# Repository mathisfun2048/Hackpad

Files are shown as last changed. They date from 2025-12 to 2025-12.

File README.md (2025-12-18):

# Arya's Hackpad Macropad!

This 9-key macropad also includes a 3x3 led aray, rotary encoder, and an OLED display. It uses KMK Firmware (learning the python library was fun!) This is my first time working with PCB so it was a fun expeirment!

I designed this to help me with photoshop, illustrator, and indesign! I also saw some cool bitmap-pattern led machines at Ikea and wanted to emulate them using a LED array. 

# Features:
- top and bottom parts for the case
- XIAO‑RP2040 as the processor
- 128x32 OLED display
- 3x3 LED array
- 3x3 switch array
- Rotary encoder to switch between key-map layers and bitmap patterns
- 9 Diodes to help with having a lot of inputs with a limited number of GPIO ports
- KMK code!
- made with my sweat and tears :D

# CAD Model

Everything fits together using 4 M3 × 16 mm pan-head screws; it will go through the case and pcb.

This has 2 seperate printed pieces, sandwiching the PCB. 

This was made using Autodesk Fusion!

Screenshot 2025-06-12 at 12 26 53 AM
_screenshot of your overall hackpad and of your case and how it'll fit together_

Fusion wasn't importing the screws, switches/keycaps, rotary, or oled, or LEDs :( but the schematics down below will better illustrate where they are supposed to be :)

# Schematic

Here is a picture of the Schematic! This was my first interaction with anything hardware so it dosn't look exactly like my final board but it was so so fun to make this! 

Screenshot 2025-06-12 at 12 30 19 AM
_screenshot of your schematic_

# PCB

Now the real thing! It was definelty more challenging to do this than the schematic because this was for real! It was definetly a processes learning that how I made my schematic wouldn't nessicarily be how it would look in the end product, but fiddeling around with it was fun. I was super into graphic design before and this was a fun application of those skills, merging art with hardware!

Screenshot 2025-06-12 at 12 32 29 AM
_screenshot of your PCB_

# Firmware

This hackpad uses KMK firmware!

Some features:

- theres a different map for each application which the encoder can rotate between!
- there is 2 modes: layer mode and bitmap mode-- the layer mode allows it to work like a macropad while in bitmap mode the enocder rotates between different pattenrs for the LED array

There will be more features later! This was just an intro to get my hackpad running. very cool stuff indeed

# BOM
Here's the official Arya-pad partlist!

- 9x MX-Style Switches (preferably brown :3 )
- 9x DSA Blank White Keycaps
- 1x EC11 rotary encoder w/ push switch
- 10x 1N4148 signal diodes
- 9x SK6812 MINI-E RGB LEDs
- 1x 0.91 in 128 × 32 OLED Pannel
- 1x Seeed XIAO RP2040
- 1x Case (2 printed parts)
- 4x M3 × 16 mm pan-head screws

# Fun Facts
This was a really fun build! I spent 3ish weeks working on it, spreading it out so I can learn the most from it! As I said before, this was my first experience with hardware design but this project has made me really excited about what I can build on my own. 

# Build Journal 6ish hours

This was my first hardware design project and it was a ton of fun learning how to solder! Bellow, I have attached some snapshots through my build journey. 









![IMG_5013](https://github.com/user-attachments/assets/8a6bfd2b-48ce-402c-
8bdf-4c33d4b0655e)


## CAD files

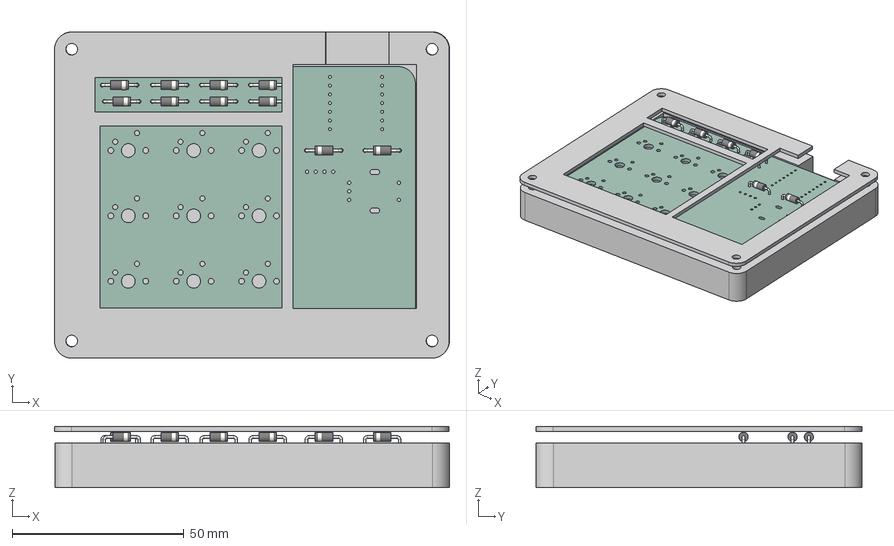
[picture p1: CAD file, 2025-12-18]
CAD/Hackpad_Arya_CAD.step
115.1 x 95.1 x 17.8 mm
D_DO-41_SOD81_P10.16mm_Horizontal x 10
aryapad_v1_PCB
Hackpad Top Plate

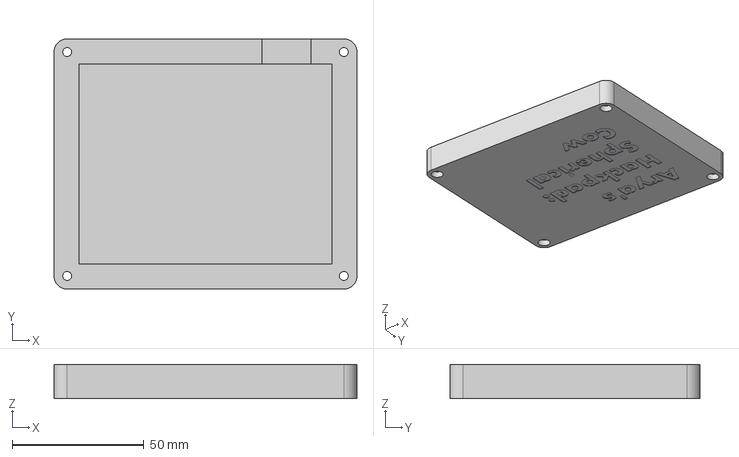
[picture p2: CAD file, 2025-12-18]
Production/bottom.step
115.0 x 95.0 x 13.0 mm

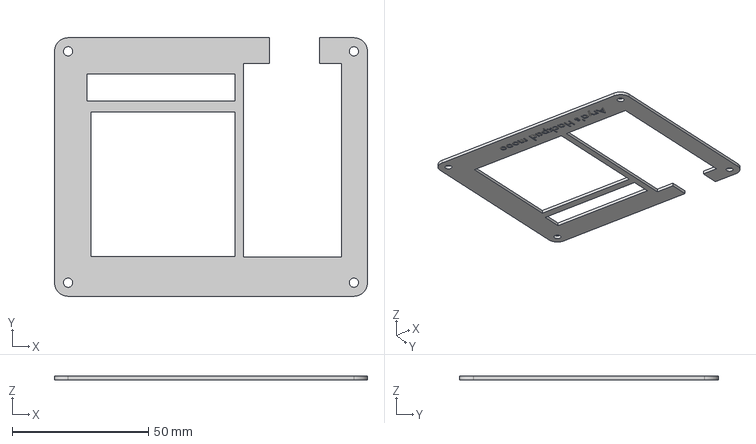
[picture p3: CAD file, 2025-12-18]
Production/top.step
115.0 x 95.0 x 1.50 mm

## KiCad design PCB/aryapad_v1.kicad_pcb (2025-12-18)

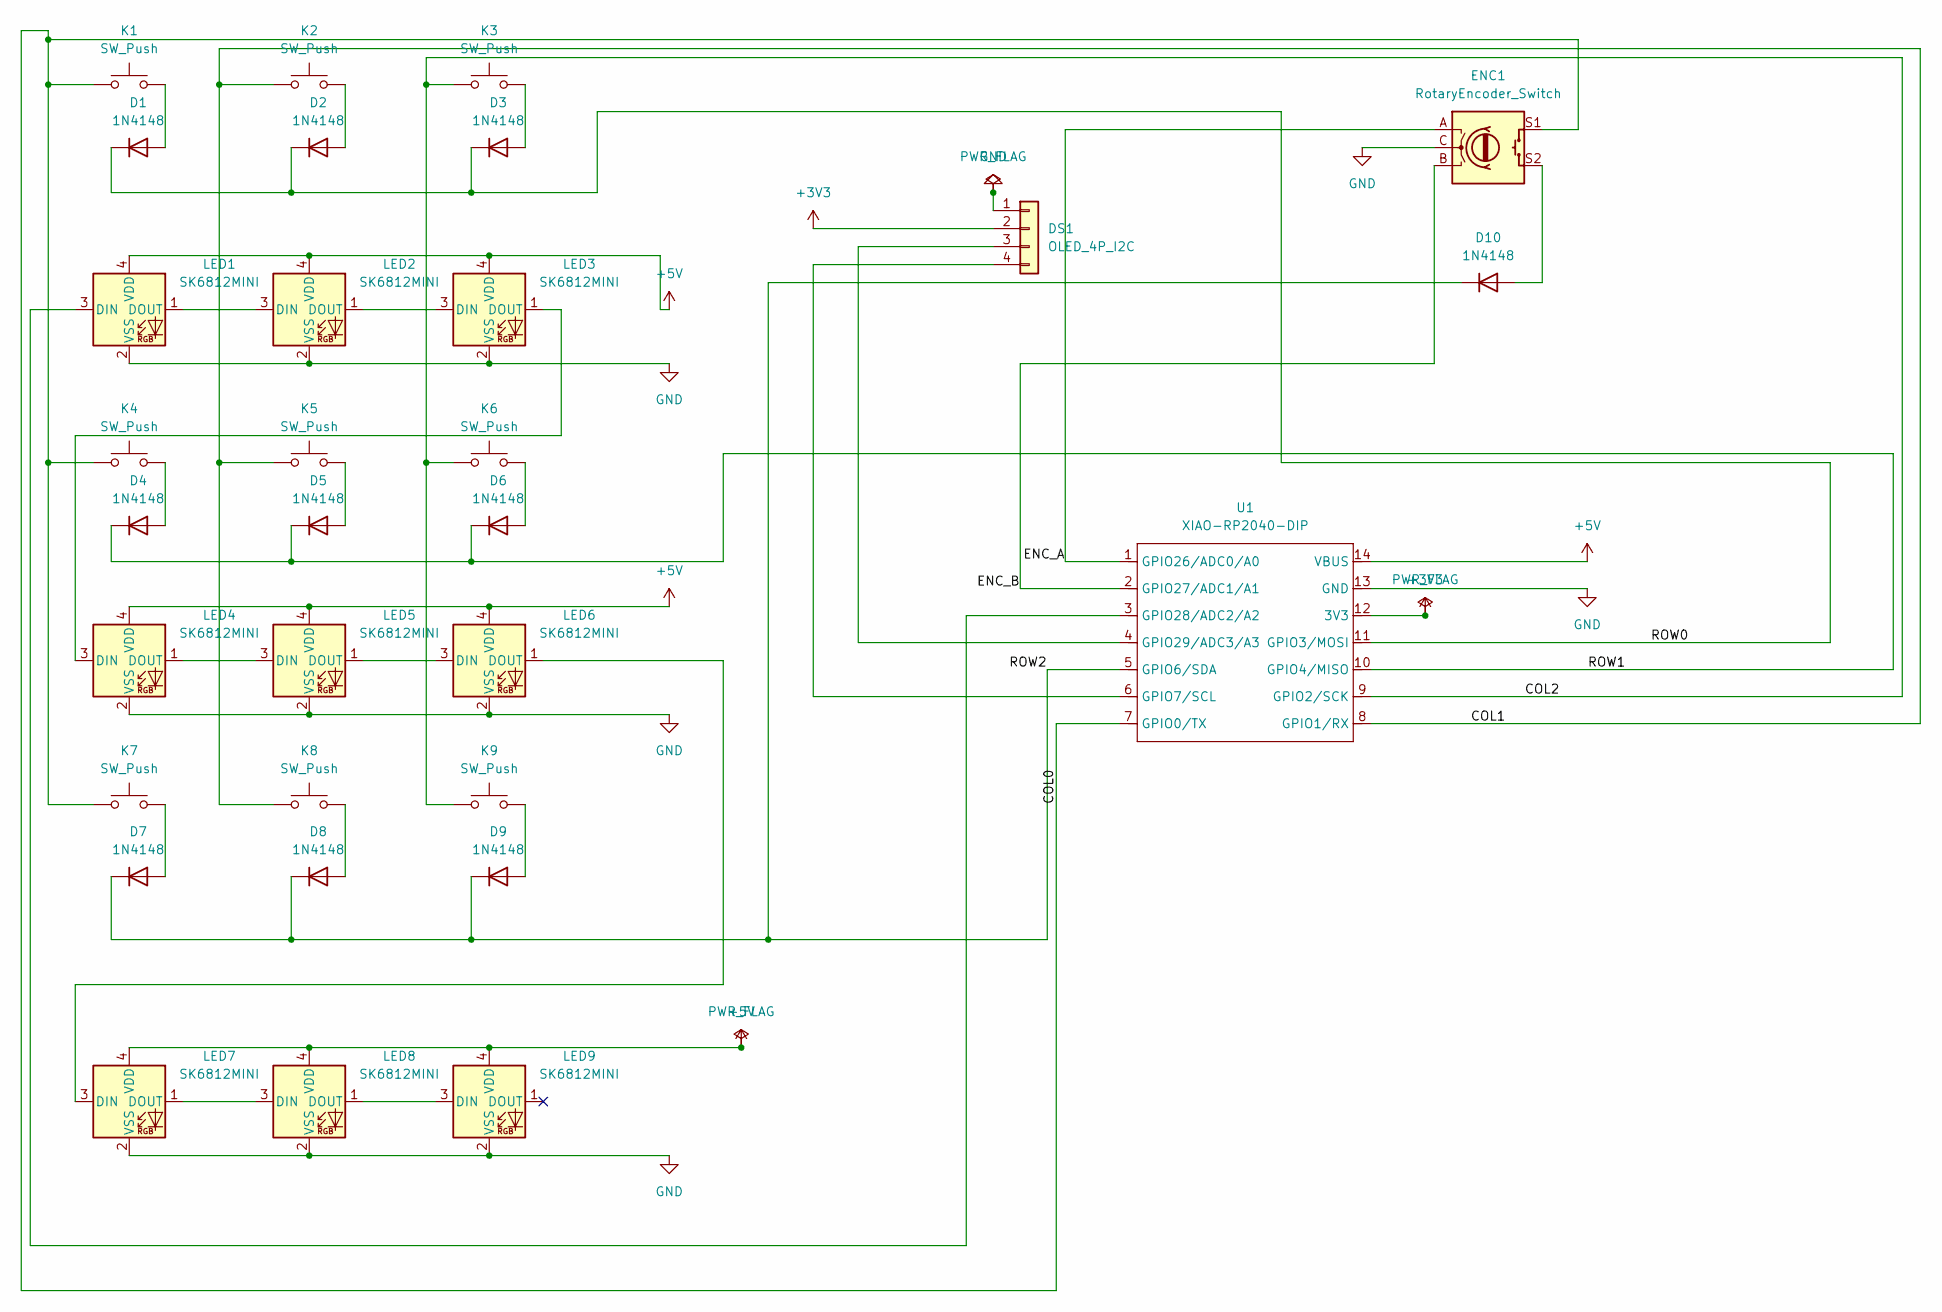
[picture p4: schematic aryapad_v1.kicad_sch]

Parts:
D1, D2, D3, D4, D5, D6, D7, D8, D9, D10: 1N4148; D_DO-41_SOD81_P10.16mm_Horizontal
DS1: OLED_4P_I2C; SSD1306-0.91-OLED-4pin-128x32
ENC1: RotaryEncoder_Switch; RotaryEncoder_Alps_EC11E-Switch_Vertical_H20mm
K1, K2, K3, K4, K5, K6, K7, K8, K9: SW_Push; SW_Cherry_MX_1.00u_PCB
LED1, LED2, LED3, LED4, LED5, LED6, LED7, LED8, LED9: SK6812MINI; LED_SK6812MINI_PLCC4_3.5x3.5mm_P1.75mm
U1: XIAO-RP2040-DIP

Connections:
+3V3: DS1.2 (VCC), U1.12 (3V3)
+5V: LED1.4 (VDD), LED2.4 (VDD), LED3.4 (VDD), LED4.4 (VDD), LED5.4 (VDD), LED6.4 (VDD), LED7.4 (VDD), LED8.4 (VDD), LED9.4 (VDD), U1.14 (VBUS)
/COL0: ENC1.S1, K1.1, K4.1, K7.1, U1.7 (GPIO0/TX)
/COL1: K2.1, K5.1, K8.1, U1.8 (GPIO1/RX)
/COL2: K3.1, K6.1, K9.1, U1.9 (GPIO2/SCK)
/ENC_A: ENC1.A, U1.1 (GPIO26/ADC0/A0)
/ENC_B: ENC1.B, U1.2 (GPIO27/ADC1/A1)
/ROW0: D1.1 (K), D2.1 (K), D3.1 (K), U1.11 (GPIO3/MOSI)
/ROW1: D4.1 (K), D5.1 (K), D6.1 (K), U1.10 (GPIO4/MISO)
/ROW2: D7.1 (K), D8.1 (K), D9.1 (K), D10.1 (K), U1.5 (GPIO6/SDA)
GND: DS1.1 (GND), ENC1.C, LED1.2 (VSS), LED2.2 (VSS), LED3.2 (VSS), LED4.2 (VSS), LED5.2 (VSS), LED6.2 (VSS), LED7.2 (VSS), LED8.2 (VSS), LED9.2 (VSS), U1.13 (GND)
unnamed: D1.2 (A), K1.2
unnamed: D2.2 (A), K2.2
unnamed: D3.2 (A), K3.2
unnamed: D4.2 (A), K4.2
unnamed: D5.2 (A), K5.2
unnamed: D6.2 (A), K6.2
unnamed: D7.2 (A), K7.2
unnamed: D8.2 (A), K8.2
unnamed: D9.2 (A), K9.2
unnamed: D10.2 (A), ENC1.S2
unnamed: DS1.3 (SCL), U1.4 (GPIO29/ADC3/A3)
unnamed: DS1.4 (SDA), U1.6 (GPIO7/SCL)
unnamed: LED1.3 (DIN), U1.3 (GPIO28/ADC2/A2)
unnamed: LED1.1 (DOUT), LED2.3 (DIN)
unnamed: LED2.1 (DOUT), LED3.3 (DIN)
unnamed: LED3.1 (DOUT), LED4.3 (DIN)
unnamed: LED4.1 (DOUT), LED5.3 (DIN)
unnamed: LED5.1 (DOUT), LED6.3 (DIN)
unnamed: LED6.1 (DOUT), LED7.3 (DIN)
unnamed: LED7.1 (DOUT), LED8.3 (DIN)
unnamed: LED8.1 (DOUT), LED9.3 (DIN)

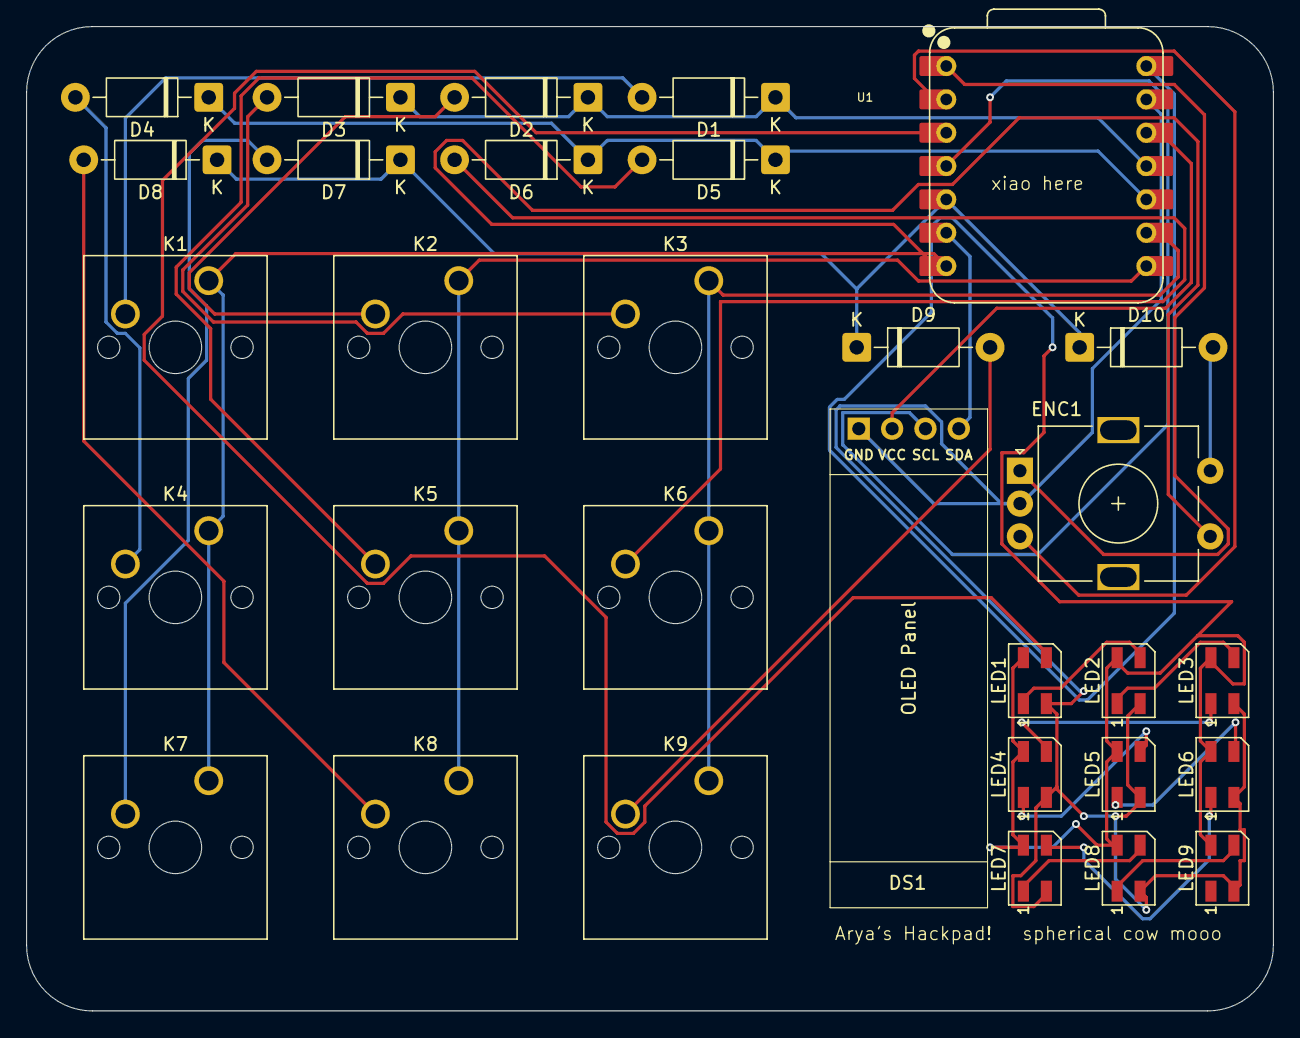
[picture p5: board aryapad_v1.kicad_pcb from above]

Board: 2 copper layers, 95.0 x 75.0 mm, 31 parts (0 on the bottom side), 32 nets.

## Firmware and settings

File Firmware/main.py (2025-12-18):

import board, busio, time, neopixel, adafruit_ssd1306
from kmk.kmk_keyboard import KMKKeyboard
from kmk.scanners.keypad import MatrixScanner
from kmk.keys import KC
from kmk.modules.layers import Layers
from kmk.modules.encoders import Encoders

# ── KMK base ──────────────────────────────────────────────────────────────
kbd = KMKKeyboard()
kbd.col_pins = (board.GP0, board.GP1, board.GP2)
kbd.row_pins = (board.GP3, board.GP4, board.GP6)
kbd.diode_orientation = MatrixScanner.Column2Row

# ── Layers & colours ──────────────────────────────────────────────────────
layers = Layers(); kbd.modules.append(layers)
BASE, JET, PS, AI, ID, MEDIA = range(6)
LAYER_ORDER = [BASE, JET, PS, AI, ID, MEDIA]
LAYER_NAMES  = ["Base", "Jet", "PS", "AI", "ID", "Media"]
LAYER_COLORS = {
    BASE : (  0, 255, 255),  # Cyan
    JET  : (255, 160,   0),  # Orange
    PS   : (255,  60,  60),  # Red
    AI   : (255, 220,   0),  # Yellow
    ID   : (160,   0, 255),  # Violet
    MEDIA: (  0, 255, 100),  # Green
}

# ── Encoder (A/B only – push wired in matrix) ─────────────────────────────
enc = Encoders(); enc.encoder_pins = ((board.GP26, board.GP27, None),)
kbd.modules.append(enc)

# ── 3×3 NeoPixel panel ───────────────────────────────────────────────────
NUM_PIXELS = 9
pixels = neopixel.NeoPixel(board.GP28, NUM_PIXELS, brightness=0.25, auto_write=False)
MAP = [[0,1,2],[3,4,5],[6,7,8]]
P = lambda r,c,clr: pixels.__setitem__(MAP[r][c], clr)

# ── 128×32 I²C OLED ───────────────────────────────────────────────────────
try:
    i2c  = busio.I2C(board.GP29, board.GP7)  # SCL, SDA
    oled = adafruit_ssd1306.SSD1306_I2C(128, 32, i2c)
    oled.fill(0); oled.show()
    OLED_OK = True
except Exception as e:
    print(f"OLED init failed → continuing headless: {e}")
    OLED_OK = False

oled_line = (lambda txt,y: oled.text(txt,0,y,1)) if OLED_OK else (lambda *a,**k: None)

# ── 16 tiny bit‑maps ───────────────────────────────────────────────────────
OFF=(0,0,0); W=(255,255,255); R=(255,40,40); G=(0,200,40)
B=(0,120,255); Y=(255,180,0)
PATTERNS = [
    [[OFF,R,OFF],[R,R,R],[OFF,R,OFF]],                 # 0 Heart
    [[OFF,B,OFF],[OFF,B,OFF],[B,B,B]],                 # 1 Up
    [[B,B,B],[OFF,B,OFF],[OFF,B,OFF]],                 # 2 Down
    [[OFF,B,OFF],[B,B,B],[OFF,B,OFF]],                 # 3 Left/Right
    [[OFF,G,OFF],[G,G,G],[OFF,G,OFF]],                 # 4 Plus
    [[OFF,OFF,OFF],[Y,Y,Y],[OFF,OFF,OFF]],             # 5 Minus
    [[R,OFF,R],[OFF,R,OFF],[R,OFF,R]],                 # 6 X
    [[W,W,W],[W,OFF,W],[W,W,W]],                       # 7 Square
    [[Y,OFF,Y],[OFF,Y,OFF],[Y,OFF,Y]],                 # 8 Checker
    [[OFF,OFF,R],[OFF,R,OFF],[R,OFF,OFF]],             # 9 / diag
    [[R,OFF,OFF],[OFF,R,OFF],[OFF,OFF,R]],             #10 \ diag
    [[OFF,OFF,OFF],[OFF,W,OFF],[OFF,OFF,OFF]],         #11 Dot
    [[OFF,OFF,OFF],[Y,OFF,Y],[OFF,Y,OFF]],             #12 Smile
    [[OFF,OFF,OFF],[OFF,R,OFF],[R,OFF,R]],             #13 Frown
    [[W,W,W],[W,W,W],[W,W,W]],                         #14 Full
    [[B,G,R],[Y,W,B],[R,G,B]],                         #15 Random
]
pat = 0
edit_mode = False
brightness = 0.25

# ── Draw helpers ───────────────────────────────────────────────────────────
last_oled = 0

def show_pattern(frame=False):
    bmp = PATTERNS[pat]
    for r in range(3):
        for c in range(3):
            P(r,c,bmp[r][c])
    if frame:
        for i in range(3):
            P(0,i,W); P(2,i,W); P(i,0,W); P(i,2,W)
    pixels.show()

def show_layer():
    ly = layers.active_layers[0] if layers.active_layers else BASE
    col = LAYER_COLORS[ly]
    for i in range(NUM_PIXELS): pixels[i]=col
    pixels.show()

def refresh_oled(force=False):
    global last_oled
    if not OLED_OK: return
    now = time.monotonic()
    if not force and now - last_oled < .1: return     # 100 ms throttle
    last_oled = now
    oled.fill(0)
    if edit_mode:
        oled_line("PX Mode",0)
        oled_line(f"{pat+1}/{len(PATTERNS)}  B{int(pixels.brightness*100)}%",10)
    else:
        ly = layers.active_layers[0] if layers.active_layers else BASE
        oled_line("Layer",0); oled_line(LAYER_NAMES[ly],10)
    oled.show()

# ── Encoder rotation ───────────────────────────────────────────────────────
last_rot = 0

def rot(step:int):
    global pat, last_rot
    now=time.monotonic()
    if now-last_rot<.05: return    # 50 ms debounce
    last_rot=now
    if edit_mode:
        pat=(pat+step)%len(PATTERNS); show_pattern(True); refresh_oled(True)
    else:
        cur=layers.active_layers[0] if layers.active_layers else BASE
        idx=LAYER_ORDER.index(cur); new=LAYER_ORDER[(idx+step)%len(LAYER_ORDER)]
        if new!=cur:
            layers.active_layers[:]=[new]; show_layer(); refresh_oled(True)

enc.encoder_callbacks=[[lambda:rot(+1),lambda:rot(-1)]]

# ── Matrix‑handled buttons ─────────────────────────────────────────────────
STATE = {'push':False,'up':False,'dn':False}
LAST  = {'push':0,'up':0,'dn':0}
DB=0.02; BR_STEP=0.05

def after_scan():
    global edit_mode, brightness
    now=time.monotonic()
    # encoder push row2 col0
    pushed=kbd.matrix.is_key_pressed(2,0)
    if pushed!=STATE['push'] and now-LAST['push']>DB:
        if pushed:
            edit_mode=not edit_mode
            (show_pattern(True) if edit_mode else show_layer())
            refresh_oled(True)
        STATE['push']=pushed; LAST['push']=now
    if edit_mode:
        # brightness up   row2 col1
        up=kbd.matrix.is_key_pressed(2,1)
        if up!=STATE['up'] and now-LAST['up']>DB:
            if up:
                brightness=min(brightness+BR_STEP,1)
                pixels.brightness=brightness; pixels.show(); refresh_oled(True)
            STATE['up']=up; LAST['up']=now
        # brightness down row2 col2
        dn=kbd.matrix.is_key_pressed(2,2)
        if dn!=STATE['dn'] and now-LAST['dn']>DB:
            if dn:
                brightness=max(brightness-BR_STEP,.05)
                pixels.brightness=brightness; pixels.show(); refresh_oled(True)
            STATE['dn']=dn; LAST['dn']=now

kbd.after_matrix_scan_callbacks.append(after_scan)

# ── Shortcut helpers ───────────────────────────────────────────────────────
C=lambda *k: KC.LCTL(*k)
A=lambda *k: KC.LALT(*k)
S=lambda *k: KC.LSFT(*k)

JET=[C(S(KC.A)), C(S(KC.N)), C(KC.E),
     C(A(KC.L)), S(KC.F10), S(KC.F9),
     S(KC.F6),   A(KC.ENTER), C(KC.P)]
PS =[KC.V, KC.B, KC.L,
     KC.M, KC.E, C(KC.D),
     C(A(KC.I)), C(A(KC.C)), C(A(S(KC.S)))]
AI =[KC.V, KC.A, KC.P,
     KC.T, KC.R, C(KC.G),
     C(S(KC.G)), C(KC.Z), C(S(KC.Z))]
ID =[KC.V, KC.T, KC.P,
     C(KC.D), C(KC.E), KC.W,
     C(KC.SEMICOLON), C(KC.N0), C(A(KC.I))]
MEDIA=[KC.MPLY,KC.MPRV,KC.MNXT,
       KC.VOLD,KC.VOLU,KC.MUTE,
       KC.BRIGHTNESS_DOWN,KC.BRIGHTNESS_UP,KC.NO]
BASE=[KC.ESC,KC.TAB,KC.MUTE,
      KC.LEFT,KC.DOWN,KC.RIGHT,
      KC.SPC,KC.UP,KC.ENT]

kbd.keymap=[BASE,JET,PS,AI,ID,MEDIA]

# ── Startup splash ─────────────────────────────────────────────────────────
print("Booting Arya‑Pad…")
pixels.brightness = brightness
show_layer(); refresh_oled(True)

if __name__=='__main__':
    kbd.go()
